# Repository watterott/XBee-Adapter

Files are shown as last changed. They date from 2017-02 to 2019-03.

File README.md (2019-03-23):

# XBee-Adapter
The XBee-Adapter is an USB to serial adapter and breakout for XBee modules.

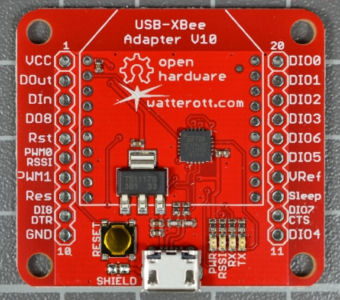
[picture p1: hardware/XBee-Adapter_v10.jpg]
XBee-Adapter


* [FTDI FT231X](https://www.ftdichip.com/Products/ICs/FT231X.html) USB UART Bridge
* 3.3V 0.8A LDO voltage regulator
* Status LEDs
* All pins available on 2.54mm headers
* microUSB-Connector
* Open-Source and released under the [Creative Commons Attribution Share-Alike License](https://creativecommons.org/licenses/by-sa/4.0/).
* **[Documentation on learn.watterott.com](https://learn.watterott.com)**

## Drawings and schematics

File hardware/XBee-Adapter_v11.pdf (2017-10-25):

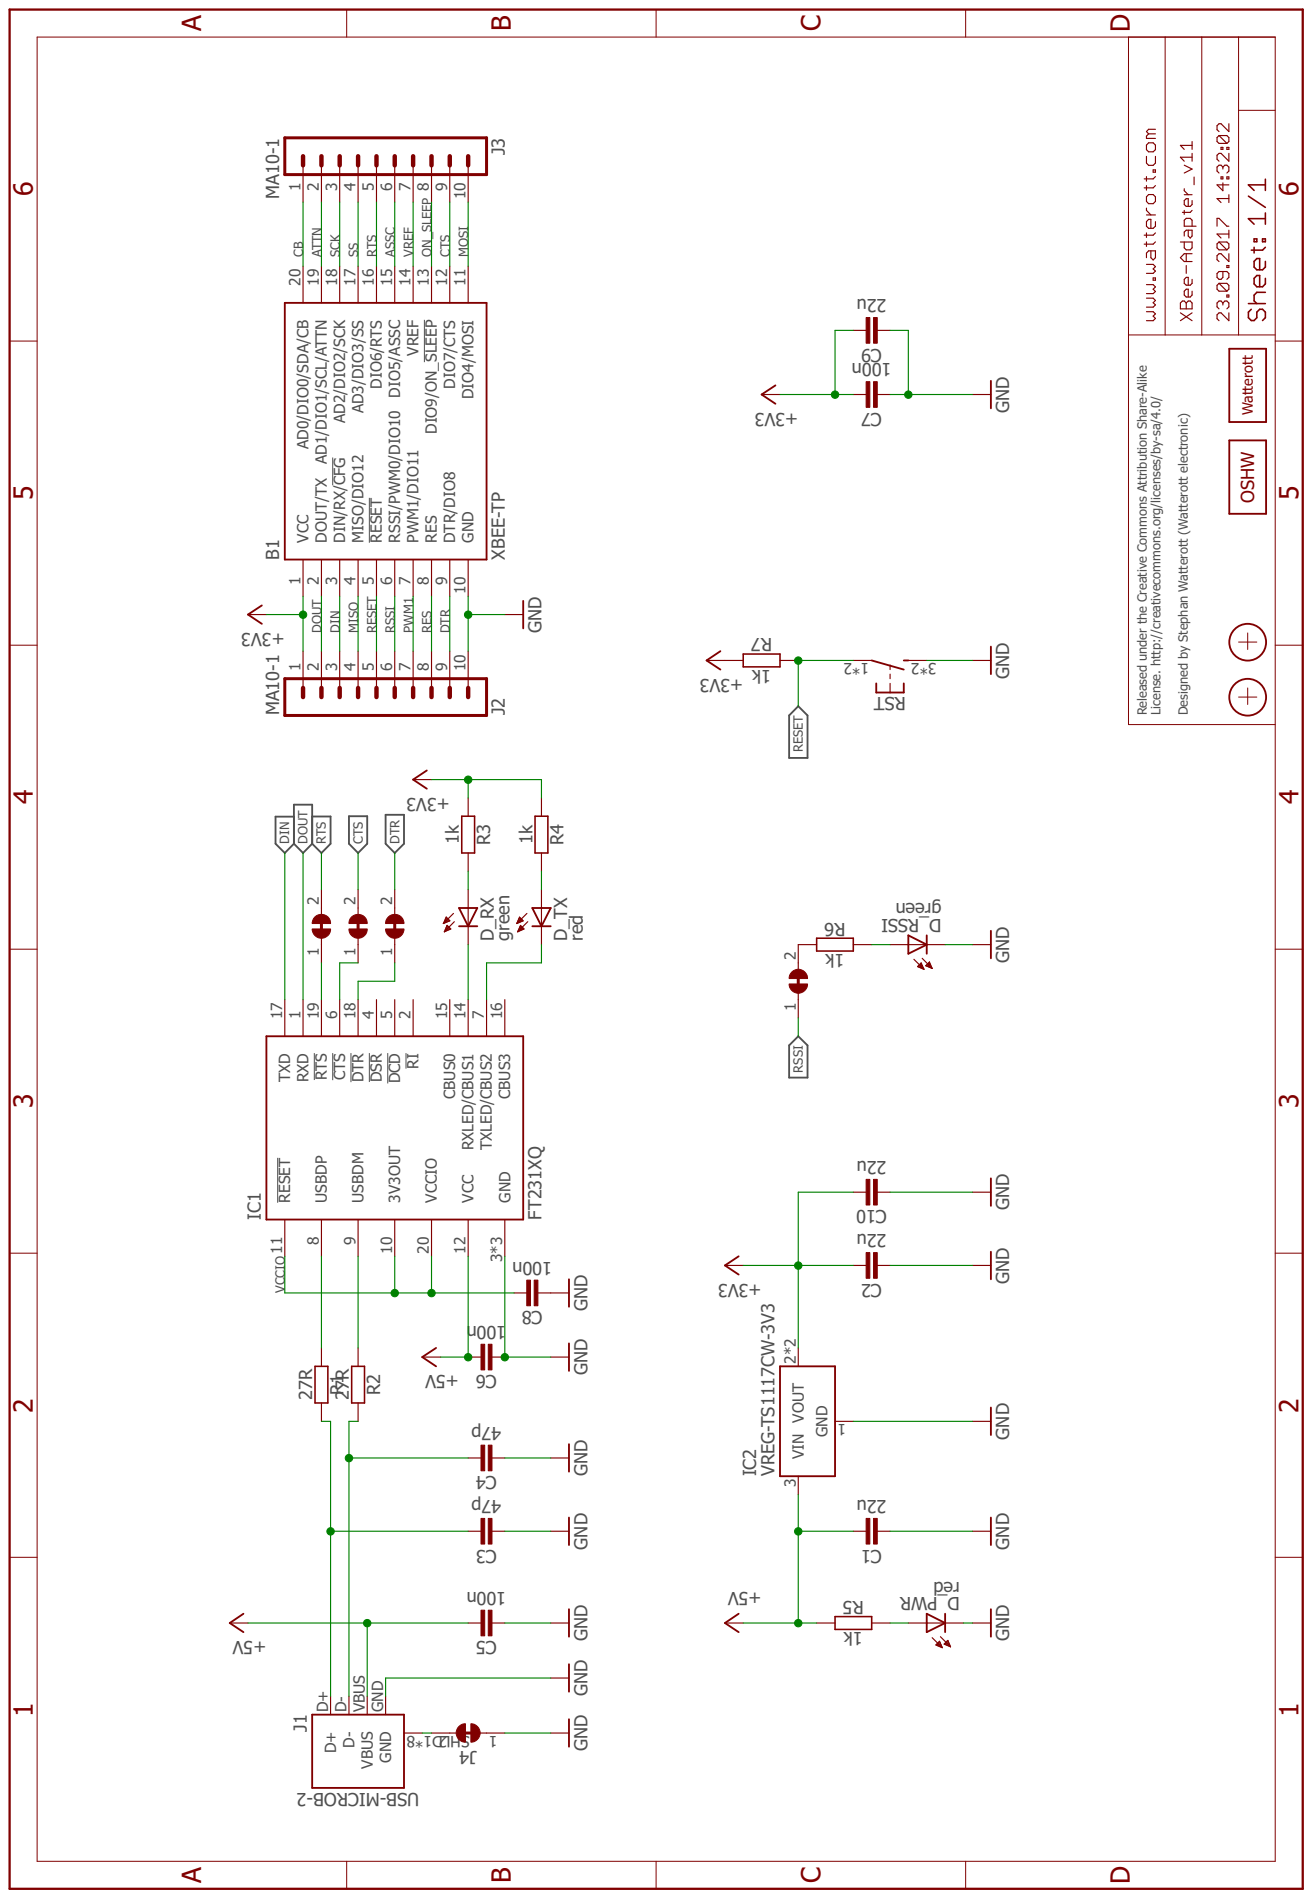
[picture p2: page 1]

FT231XQ u22 27R der u22 GND GND GND GND 27R p74 p74 GND GND green red 1k1k n001 GND n001 GND 3V3 + k1 GND 3V3 + V5 + V5 + V5 + 3V3 + GND GND MA10-1 MA10-1 n001 3V3 + GND VREG-TS1117CW-3V3 neer g k1 GND GND n001 GND k1 3V3 + u22 u22 GND Released under the Creative Commons At ribution Share-Alike License. http://creativecommons.org/licenses/by-sa/4.0/ Designed by Stephan Watterott (Watterott electronic) IC13V3OUT 10 USBDM 9 USBDP 8 RESET 11 GND 3*3 TXD 17 RXD 1 RTS 19 CTS 6 DTR 18 DSR 4 DCD 5 RI 2 CBUS0 15 VCCIO 20 VCC 12 RXLED/CBUS1 14 TXLED/CBUS2 7 CBUS3 16 1C R1 D+ D+ D- D- VBUS VBUS GND GND J1 2- BORCI M- BSU8*1DL HS R WP_D 2C R2 3C4CD_RX D_TX R3R4 5C6C 5R J2 12345678910 J3 12345678910 7C IC2 GND VIN 3 V1 OUT 2*2 6R I SSR_D 4J 2 1 2 1 2 1 2 12 1 VCC 1 DOUT/TX 2 DIN/RX/CFG 3 MISO/DIO12 4 RESET 5 RSSI/PWM0/DIO10 6 PWM1/DIO11 7 RES 8 DTR/DIO8 9 GND 10 DIO4/MOSI 11 DIO7/CTS 12 DIO9/ON_SLEEP 13 VREF 14 DIO5/ASSC 15 DIO6/RTS 16 AD3/DIO3/SS 17 AD2/DIO2/SCK 18 AD1/DIO1/SCL/AT N 19 AD0/DIO0/SDA/CB 20 B1XBEE-TP 8C 7R 9CTSR 2*1 2*3 01C VCCIO RTS RTS CTS CTS DOUT DOUT DIN DIN MISO RESET RESET RSSI RSSI PWM1 RES DTR DTR CBAT N SCK SSASSC VREF ON_SLEEP MOSI ABCD 1 2 3 4 5 6 ABCD 1 2 3 4 5 6 OSHW Watterott

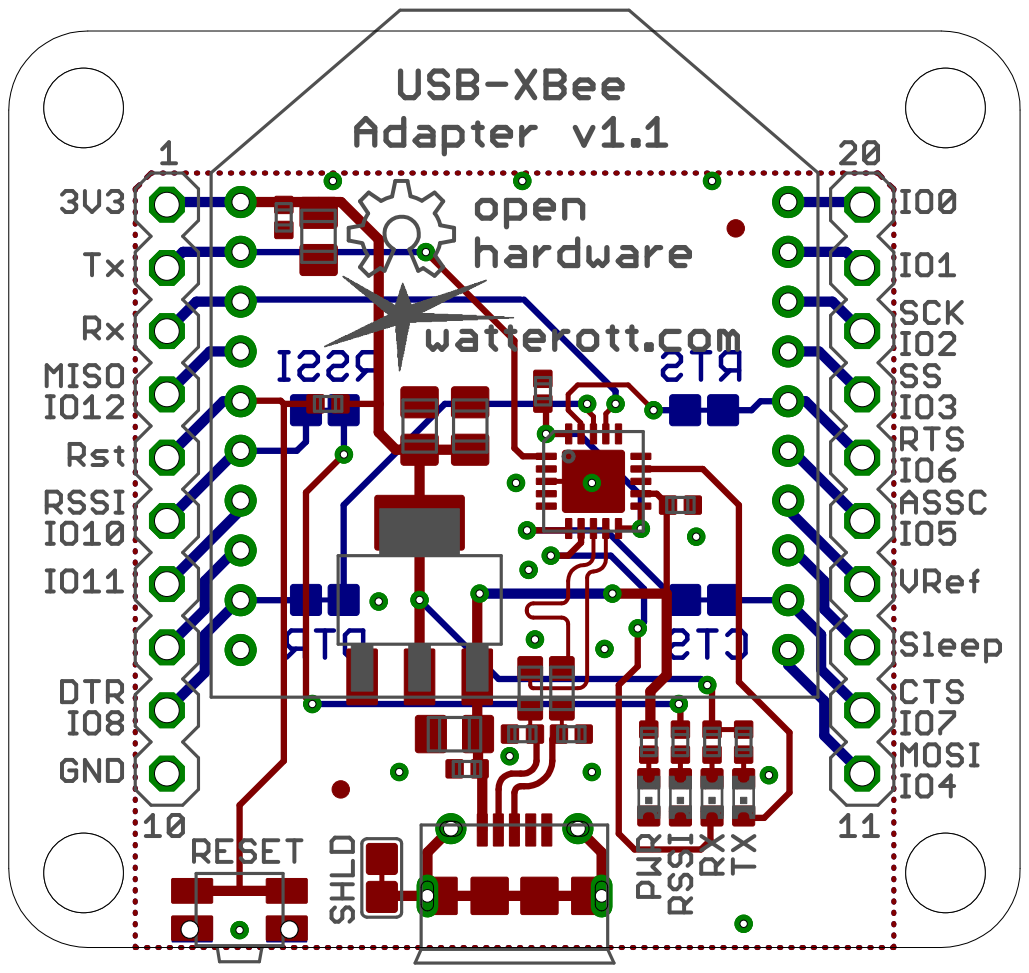
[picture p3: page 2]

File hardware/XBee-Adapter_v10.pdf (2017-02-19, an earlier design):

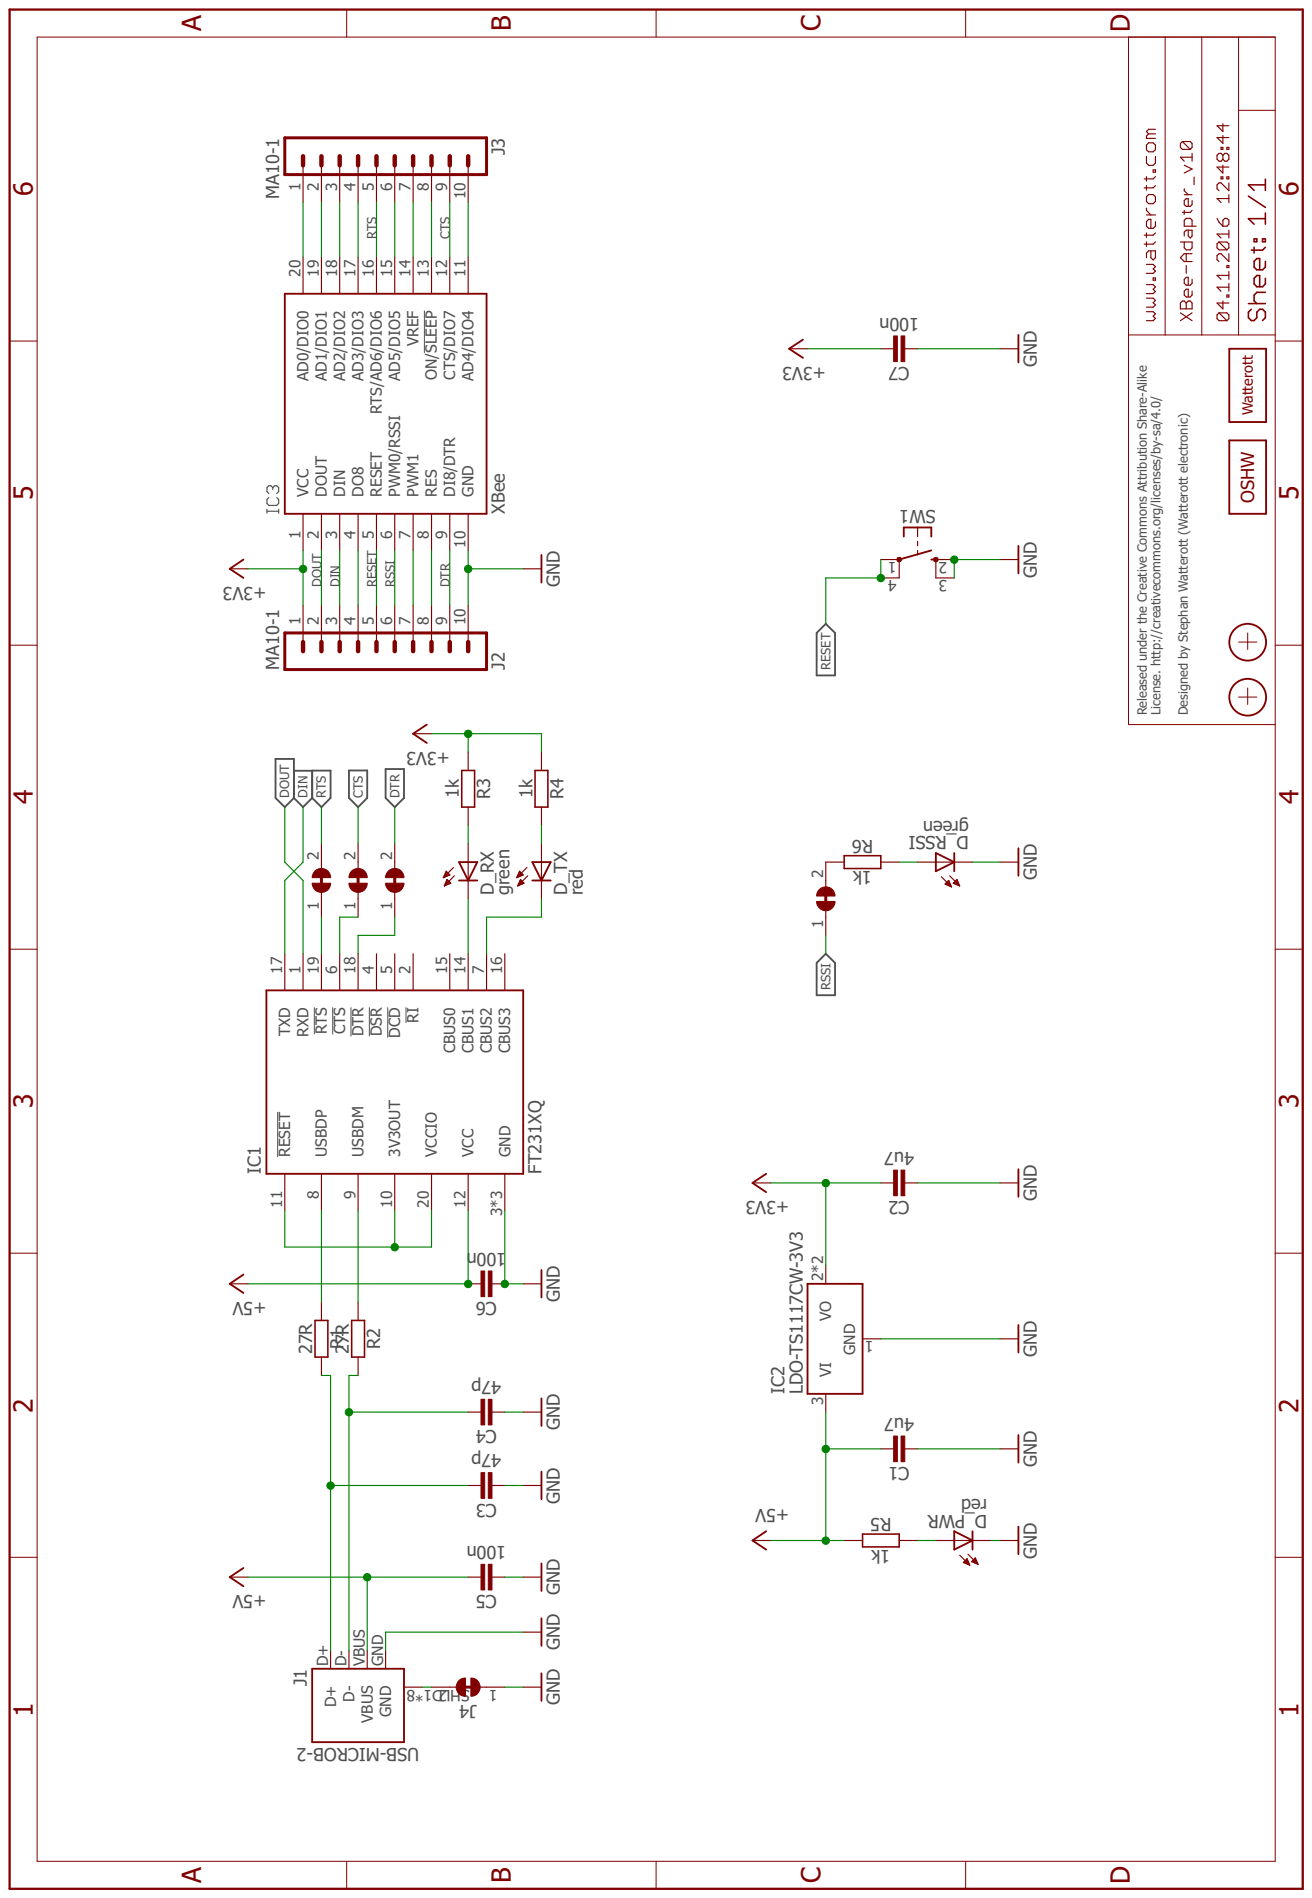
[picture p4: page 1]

FT231XQ 7u4 27R der 7u4 GND GND GND GND 27R p74 p74 GND GND green red 1k1k n001 GND n001 GND 3V3 + k1 GND 3V3 + V5 + V5 + V5 + 3V3 + GNDGND MA10-1 MA10-1 n001 3V3 + GND LDO-TS1117CW-3V3 neer g k1 GND GND Released under the Creative Commons At ribution Share-Alike License. http://creativecommons.org/licenses/by-sa/4.0/ Designed by Stephan Watterott (Watterott electronic) IC13V3OUT 10 USBDM 9 USBDP 8 RESET 11 GND 3*3 TXD 17 RXD 1 RTS 19 CTS 6 DTR 18 DSR 4 DCD 5 RI 2 CBUS0 15 VCCIO 20 VCC 12 CBUS1 14 CBUS2 7 CBUS3 16 1C R1 D+ D+ D- D- VBUS VBUS GND GND J1 2- BORCI M- BSU8*1DL HS R WP_D 2C R2 3C4CD_RX D_TX R3R4 5C6C 5R VCC 1 DOUT 2 DIN 3 DO8 4 RESET 5 PWM0/RSSI 6 PWM1 7 RES 8 DI8/DTR 9 GND 10 AD4/DIO4 11 CTS/DIO7 12 ON/SLEEP 13 VREF 14 AD5/DIO5 15 RTS/AD6/DIO6 16 AD3/DIO3 17 AD2/DIO2 18 AD1/DIO1 19 AD0/DIO0 20 XBee J2 12345678910 J3 12345678910 7C IC2 GND VI 3 1 VO 2*2 1 WS 1 2 4 3 6R I SSR_D 4J 2 1 2 1 2 1 2 1 2 1 RTS RTS CTS CTS DOUT DOUT DIN DIN RESET RESET RSSI RSSI DTR DTR ABCD 1 2 3 4 5 6 ABCD 1 2 3 4 5 6 OSHW Watterott

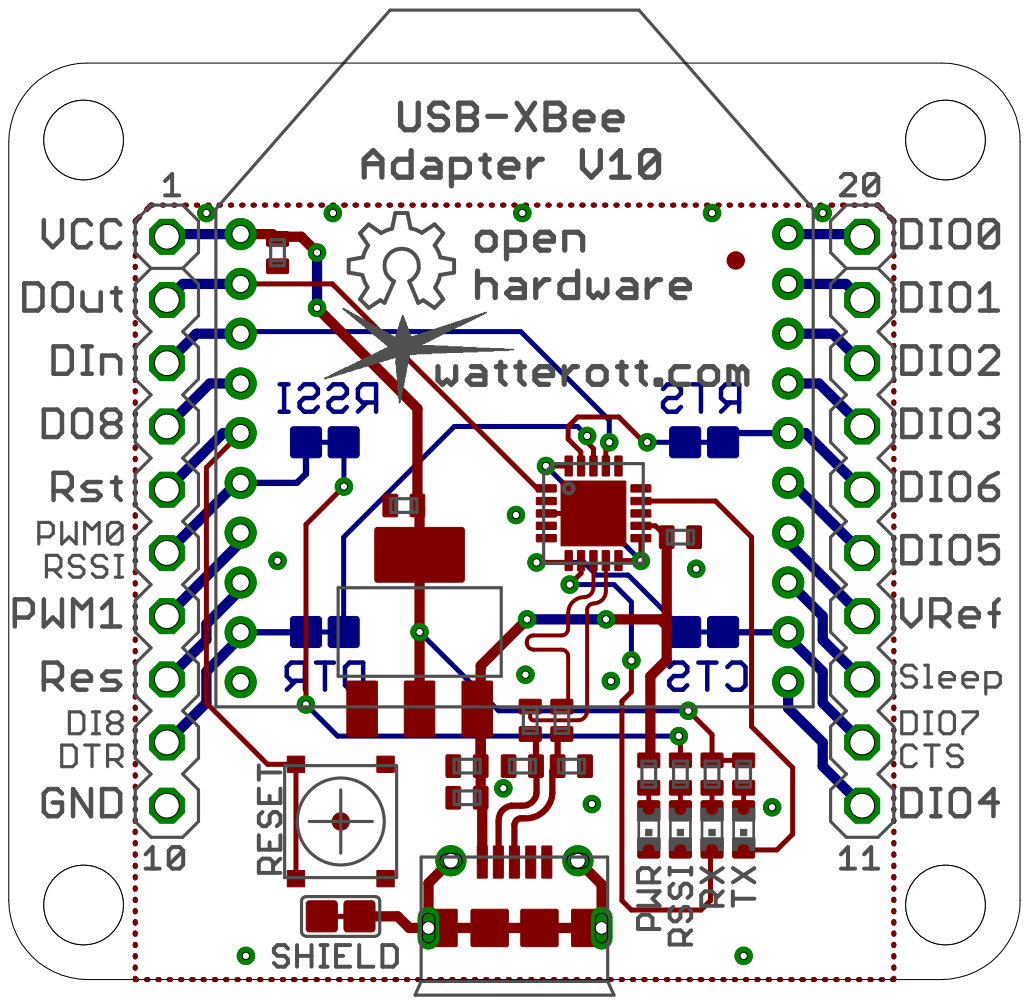
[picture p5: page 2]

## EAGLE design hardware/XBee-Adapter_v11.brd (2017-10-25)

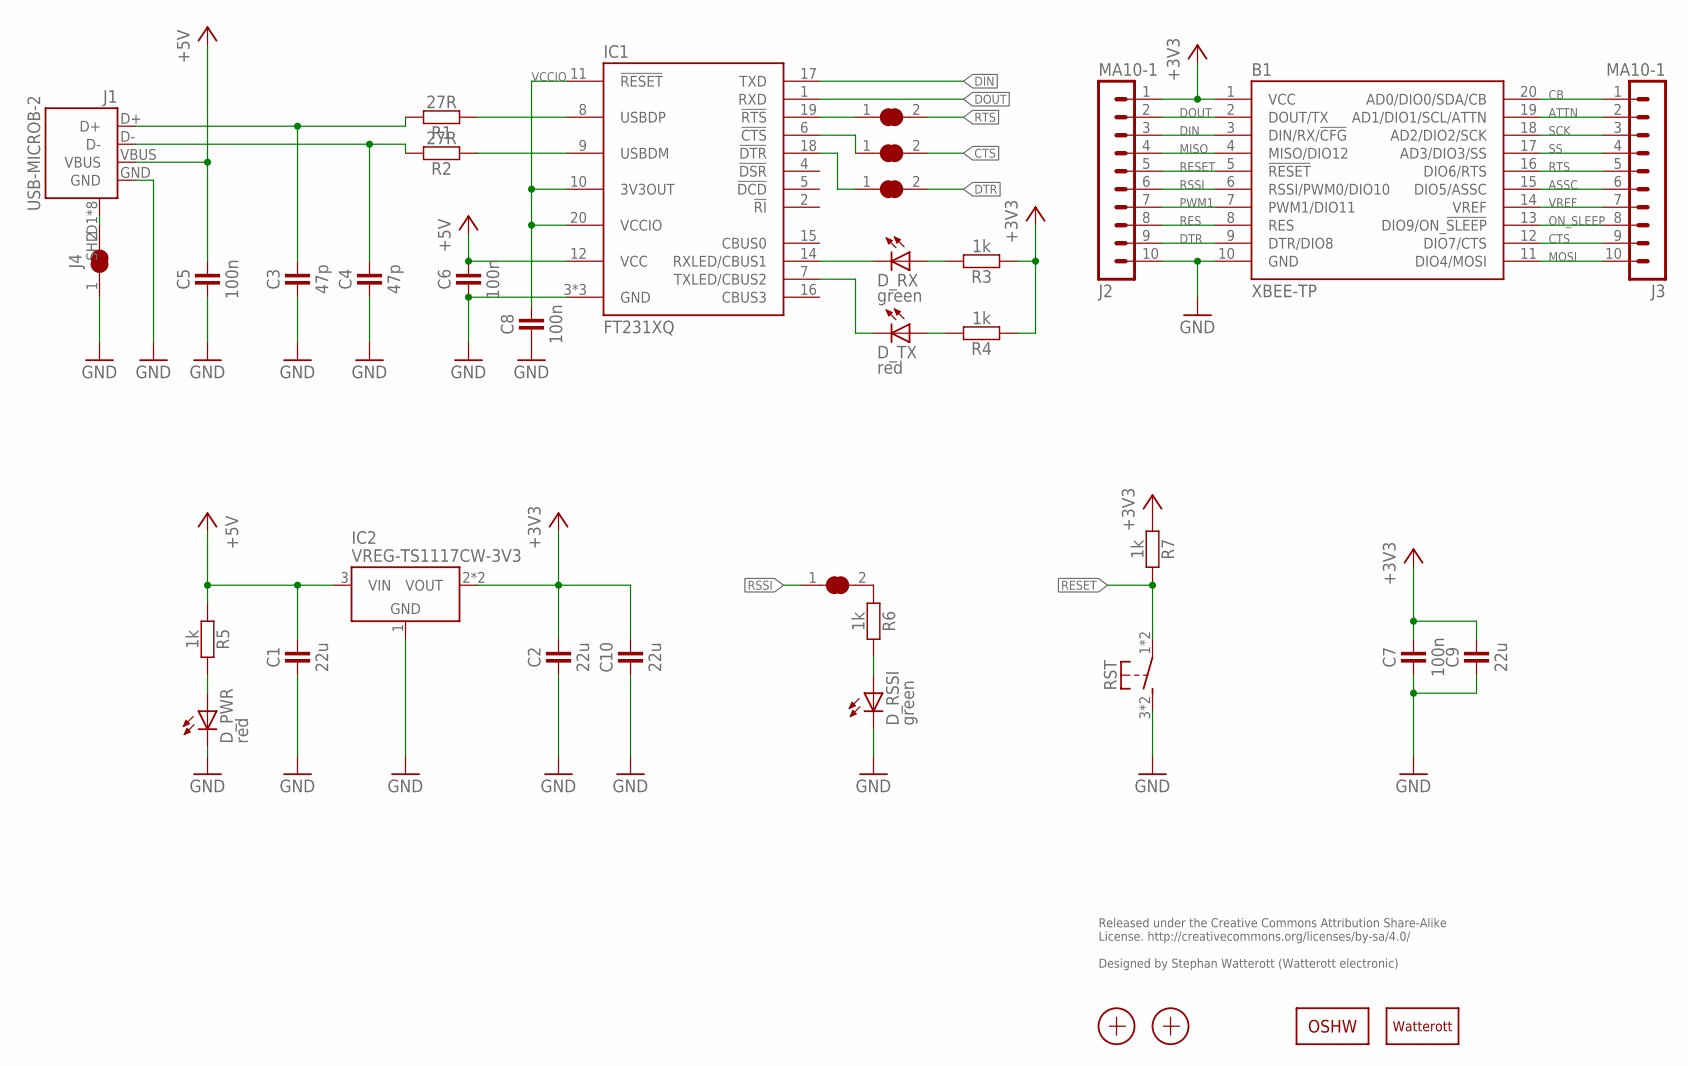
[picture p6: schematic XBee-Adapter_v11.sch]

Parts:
B1: XBEE-TP; XBEE_TP
C1, C2, C9, C10: 22u; C0805
C3, C4: 47p; C0402
C5, C6, C7, C8: 100n; C0402
CTS: JUMPER2-0603
DTR: JUMPER2-0603
D_PWR: red; C0603
D_RSSI: green; C0603
D_RX: green; C0603
D_TX: red; C0603
IC1: FT231XQ; QFN20-PAD
IC2: VREG-TS1117CW-3V3; SOT223
J1: USB-MICROB-2; USB-MICROB-10118194
J2, J3: MA10-1
J4: JUMPER2-0603
LOGO1: OSHW_LOGOX0150; OSHW_6X150
LOGO2: LOGO-S_PLACE_M; SPARK_TPLACE_M
R1, R2: 27R; C0603
R3, R4, R5, R6, R7: 1k; C0402
RSSI: JUMPER2-0603
RST: SW-TACTILE-PTS840P; PTS840P
RTS: JUMPER2-0603
X1, X2: PASSER-07; PASSER_07MM

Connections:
+3V3: B1.1 (VCC), C2.2, C7.2, C9.2, C10.2, IC2.2 (VOUT), IC2.4 (VOUT), J2.1, R3.1, R4.1, R7.1
+5V: C1.2, C5.2, C6.2, IC1.12 (VCC), IC2.3 (VIN), J1.VBUS, R5.1
ASSC: B1.15 (DIO5/ASSC), J3.6
ATTN: B1.19 (AD1/DIO1/SCL/ATTN), J3.2
CB: B1.20 (AD0/DIO0/SDA/CB), J3.1
CTS: B1.12 (DIO7/CTS), CTS.2, J3.9
DIN: B1.3 (DIN/RX/!CFG!), IC1.17 (TXD), J2.3
DOUT: B1.2 (DOUT/TX), IC1.1 (RXD), J2.2
DTR: B1.9 (DTR/DIO8), DTR.2, J2.9
D_N: C4.2, J1.D-, R2.2
D_P: C3.2, J1.D+, R1.2
GND: B1.10 (GND), C1.1, C2.1, C3.1, C4.1, C5.1, C6.1, C7.1, C8.1, C9.1, C10.1, D_PWR.C, D_RSSI.C, IC1.3 (GND), IC1.13 (GND), IC1.TP (GND), IC2.1 (GND), J1.GND, J2.10, J4.1, RST.3 (S1), RST.4 (S1)
MISO: B1.4 (MISO/DIO12), J2.4
MOSI: B1.11 (DIO4/MOSI), J3.10
unnamed: D_PWR.A, R5.2
unnamed: D_RSSI.A, R6.2
unnamed: R6.1, RSSI.2
unnamed: J1.SHLD1 (SHIELD), J1.SHLD2 (SHIELD), J1.SHLD3 (SHIELD), J1.SHLD4 (SHIELD), J1.SHLD5 (SHIELD), J1.SHLD6 (SHIELD), J1.SHLD7 (SHIELD), J1.SHLD8 (SHIELD), J4.2
unnamed: IC1.19 (!RTS), RTS.1
unnamed: CTS.1, IC1.6 (!CTS)
unnamed: D_RX.C, IC1.14 (RXLED/CBUS1)
unnamed: D_TX.C, IC1.7 (TXLED/CBUS2)
unnamed: D_RX.A, R3.2
unnamed: D_TX.A, R4.2
unnamed: DTR.1, IC1.18 (!DTR)
ON_SLEEP: B1.13 (DIO9/ON_!SLEEP!), J3.8
PWM1: B1.7 (PWM1/DIO11), J2.7
RES: B1.8 (RES), J2.8
RESET: B1.5 (!RESET!), J2.5, R7.2, RST.1, RST.2 (P1)
RSSI: B1.6 (RSSI/PWM0/DIO10), J2.6, RSSI.1
RTS: B1.16 (DIO6/RTS), J3.5, RTS.2
SCK: B1.18 (AD2/DIO2/SCK), J3.3
SS: B1.17 (AD3/DIO3/SS), J3.4
USB_N: IC1.9 (USBDM), R2.1
USB_P: IC1.8 (USBDP), R1.1
VCCIO: C8.2, IC1.10 (3V3OUT), IC1.11 (!RESET), IC1.20 (VCCIO)
VREF: B1.14 (VREF), J3.7

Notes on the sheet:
Released under the Creative Commons Attribution Share-Alike License. http://creativecommons.org/licenses/by-sa/4.0/ Designed by Stephan Watterott (Watterott electronic)

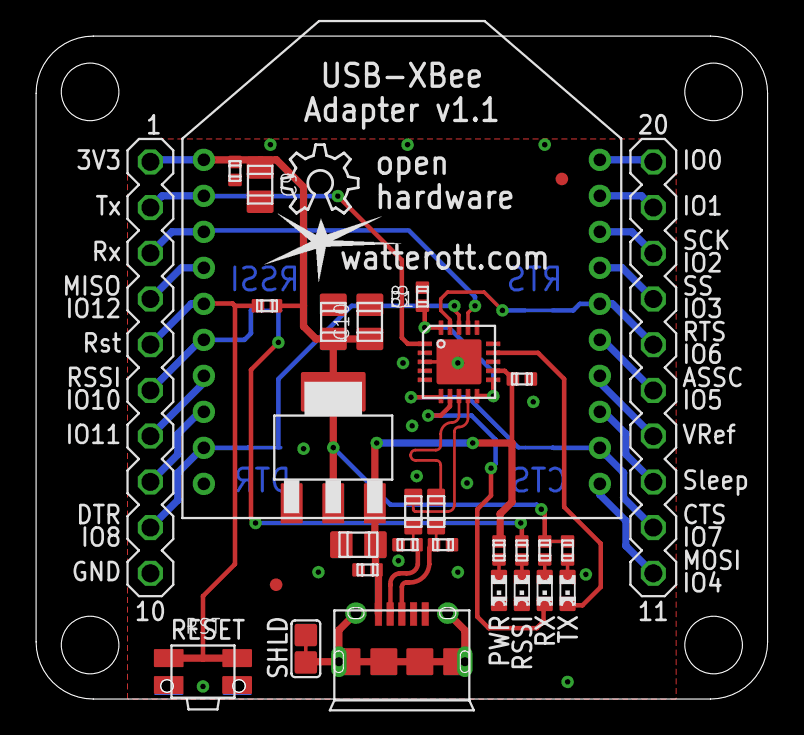
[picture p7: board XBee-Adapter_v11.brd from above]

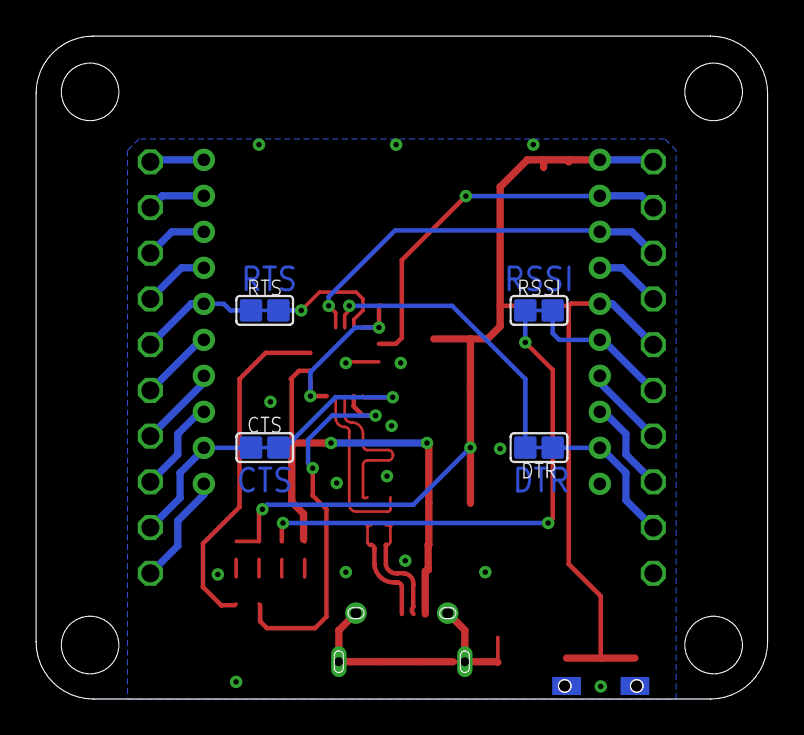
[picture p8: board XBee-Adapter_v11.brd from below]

Board: 2 copper layers, 40.6 x 36.8 mm, 37 parts (4 on the bottom side), 37 nets.
